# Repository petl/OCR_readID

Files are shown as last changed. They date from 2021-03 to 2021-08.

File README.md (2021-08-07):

<p><h2> Motivation </h2> </p>
<p>How do you track people coming and going into rooms during Covid19? Right, you save the RFID tag off their ID card! Thing is, not all IDs have RFID and more so, not all of the tag IDs are easily matched to user IDs.. To get around this we can just take a photo and read off any number we want. That's easy and quickly modifiable for different ID cards.  </p><br>
<p>Long story short: The project uses <a href='https://github.com/tesseract-ocr/tesseract'>tesseract</a> to do optical character recognition (OCR) on a photo taken from the ID card. This is then fed into a server which saves the original picture with the read number.</p><br>

<p>If you're interested in this project, take a look at the <a href='https://quiescentcurrent.com/blog/post.php?p_id=66'>blog post</a> or just write a message or leave a comment. </p><br><br>

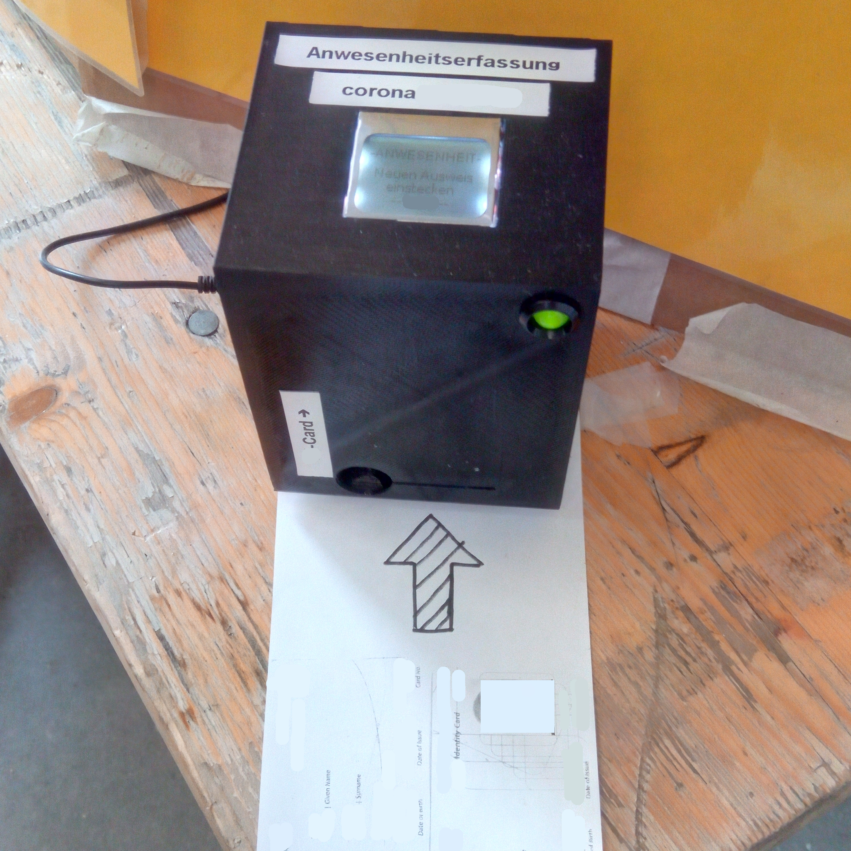
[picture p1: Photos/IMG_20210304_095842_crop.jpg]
<p align="right"><br>Photo of the reader in action.</p>  <br />

<p><h2> Hardware </h2> </p>

<p>The stuff you have to buy is quite straight forward:  <br>
 <ul>
  <li>Raspberry Pi zero with SD card</li>
  <li>Raspberry Pi cam </li>
  <li>Display Nokia 5110 / PCD8544 </li>
  <li>2x LED white</li>
  <li>1x LED greed/red</li>
  <li>3x 220 Ohm resistors </li>
  <li>2.5mm DC barrel connector </li>
  <li>Some wires and heatshrink tube</li>
  <li>4x M3x12 screws</li>
</ul> <br>
I'm not including part numbers as most of the stuff was bought from ebay and can be found by posting the description in the searchbar will find the cheapest option. <br>
</p>

<p><h2> 3D printed hardware </h2> </p>

<p>
The case is made out of two 3D printed parts. They are optimized to use as little filament as possible and don't need any support while printing. <br><br>
If you take a look at the rendering, you can see that the case is mostly empty. The inner chamber is on the top equipped with the camera and one or two LEDs and on the bottom the ID card can slide in from the front. This ensures that the camera always has the same perspective and reading stuff off the picture is straight forward. Around the inner chamber I've left enough space to fit in all the electronics and wires. The final design has two sand filled bags on each side to weigh everything down. Otherwise the box gets shifted around while inserting the ID and feels quite flimsy. 

</p>
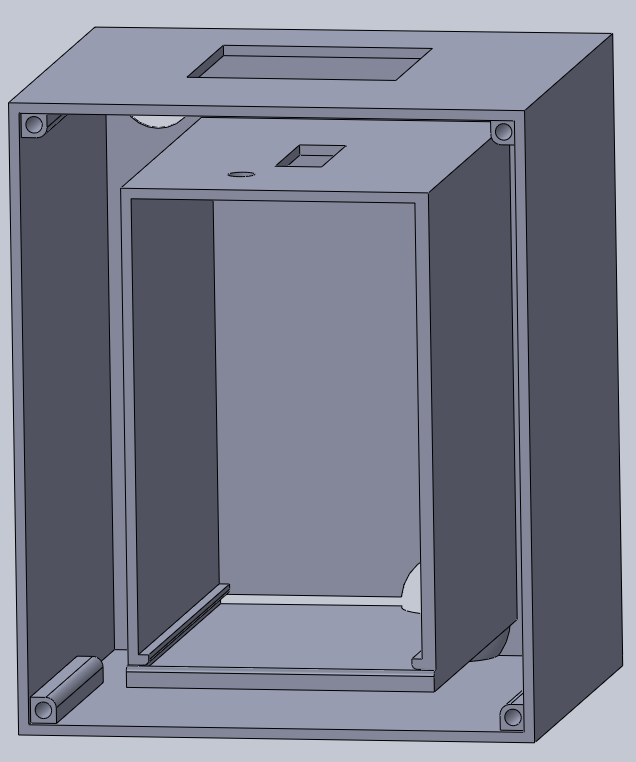
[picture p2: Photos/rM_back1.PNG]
<p align="right"><br>Rendering of the main 3D printed part. </p>  <br />

<p><h2> Electronics </h2> </p>

<p>
The reader was designed to use as little electronics as possible. This reflects in not using an eject mechanism or endswitch for card detection. It has an old Nokia 5110 Display which is super cheap on ebay and a two colour LED for user feedback. There are no buttons or any option for the user to interact with the unit, besides pushing in an ID. The schematics are below, note that the two white LEDs are just for illumination purposes.
</p>
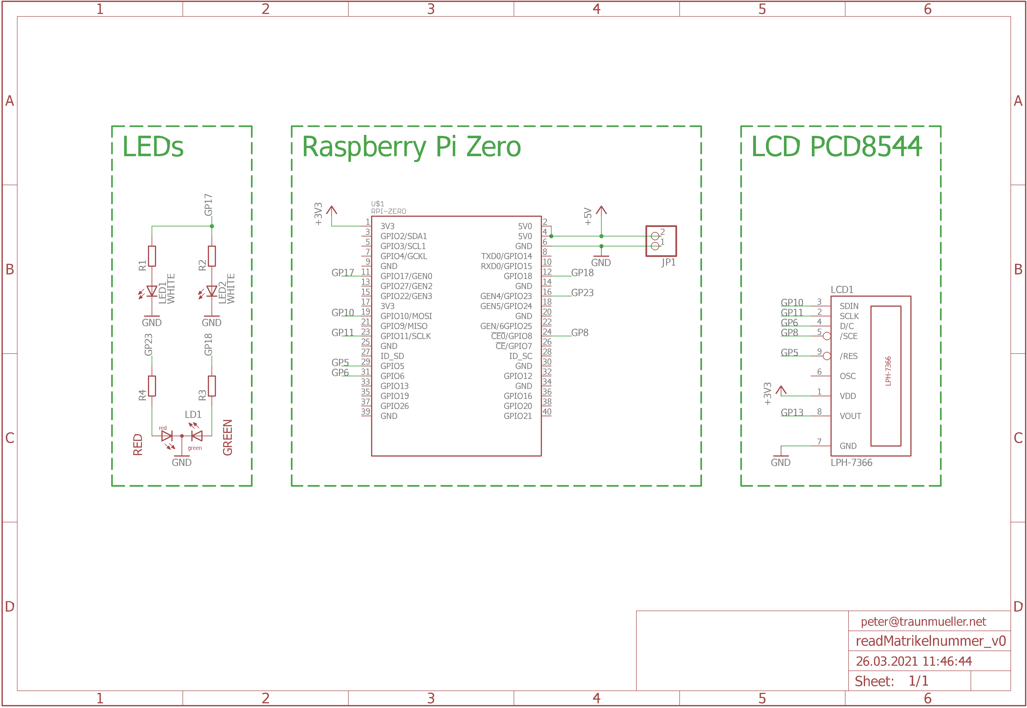
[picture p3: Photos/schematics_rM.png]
<p align="right"><br>Schematics. </p>  <br />

<p><h2> Software </h2> </p>

<p>
Obviously all the code is written in python. Actually it's not that obvious, but there is a nice library doing most of the tesseract interaction for me, so that's that. Please note that the guide includes training data. I've trained the tesseract according to some tutorial and would not recommend you doing so unless you have a good set to start with. I've done training with a limited set of a few cards and it actually made the OCR worse. To get everything running, you can work your way down this list: <br>
 <ul>
  <li><a href='https://projects.raspberrypi.org/en/projects/raspberry-pi-setting-up'>set up the RPi</a>  </li>
  <li>> sudo apt get update && upgrade </li>
  <li>> sudo apt-get install tesseract-ocr </li>
  <li>> sudo apt-get install python3-pip </li>
  <li>> sudo pip3 install pytesseract </li>
  <li>> sudo pip3 install picamera </li>
  <li>> sudo pip3 install adafruit-circuitpython-pcd8544 </li>
  <li>> sudo apt-get install ttf-dejavu </li>
  <li>> sudo apt-get install python3-pil </li>
  <li>optionally, if you have training data: > sudo cp /home/pi/tesseract_training/tesstrain/data/USERcard.traineddata  /usr/share/tesseract-ocr/4.00/tessdata/ </li>
</ul> <br>
</p>

<p>To run the code, start it with start_readMatrikelnummer.sh from the <a href='https://github.com/petl/OCR_readID/tree/main/RPi'>githubi</a>.<br>
It continuously takes photos of the chamber and compared the right most edge brightness to a set value. If this gets bright enough, it takes a photo. This is shown by blinking the red/green LEDs and the photo is saved. After the Photo is taken, the display tells you to take out the card and stops the blinking. Parallel to that it cuts out the part of the image where the interesting number could be and does an OCR on that. If it doesn't detect a plausible number, it takes a second part of the image and does the OCR there. This routine can be expanded infinitely for different cards with different positions for the numbers. If it at some point detects a valid number it opens a URL to upload the number and corresponding image to a server via PHP. </p><br>

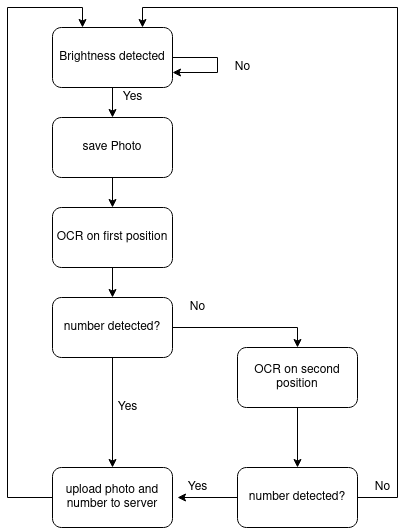
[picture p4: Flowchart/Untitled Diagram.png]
<p align="right"><br>Flowchart for the code. </p>  <br />

<p><h2> Server  </h2> </p>

<p>
If a plausible input is detected, the image and number get uploaded to a server via PHP. The server side is really low level and doesn't need a database or any other thing besides PHP. It checks all the uploaded items for their creation date everythime someone opens the page and deletes everything that is older than 14days.
</p>
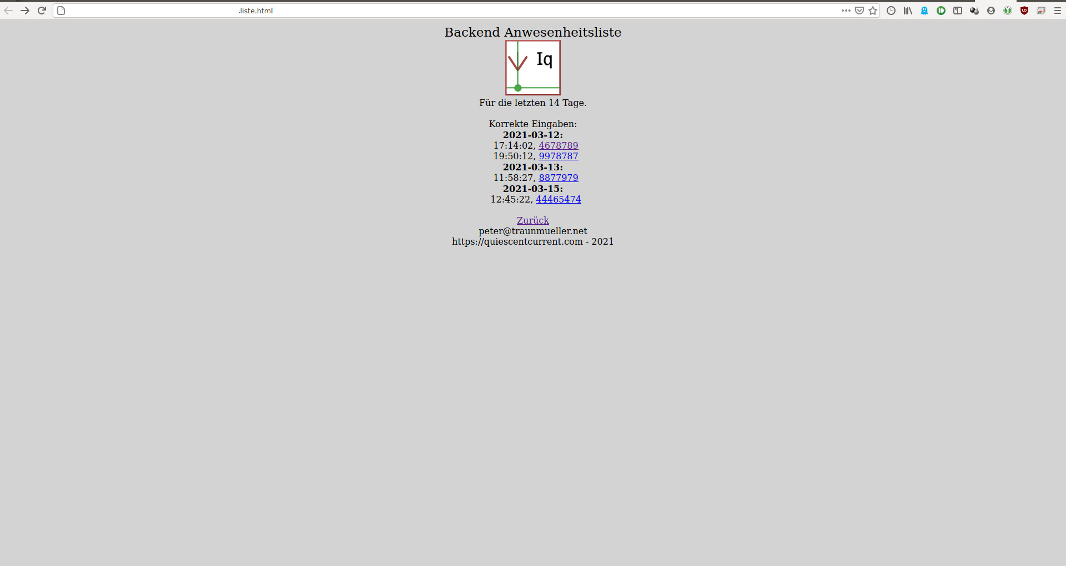
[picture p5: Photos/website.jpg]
<p align="right"><br>Backend on the server. </p>  <br />

<p><h2> Assembly </h2> </p>

<p>
Bringing everything together is not difficult and only requires some hot glue. Due to the spacious inner part of the box, all the cables and the pi perfectly fit with still some space left. 
</p>
<p align="right"><br>Half assembled unit. </p>  <br />
The additional space is then filled with two sand filled bags to make the unit heavier and give it a more robust feeling. <br>
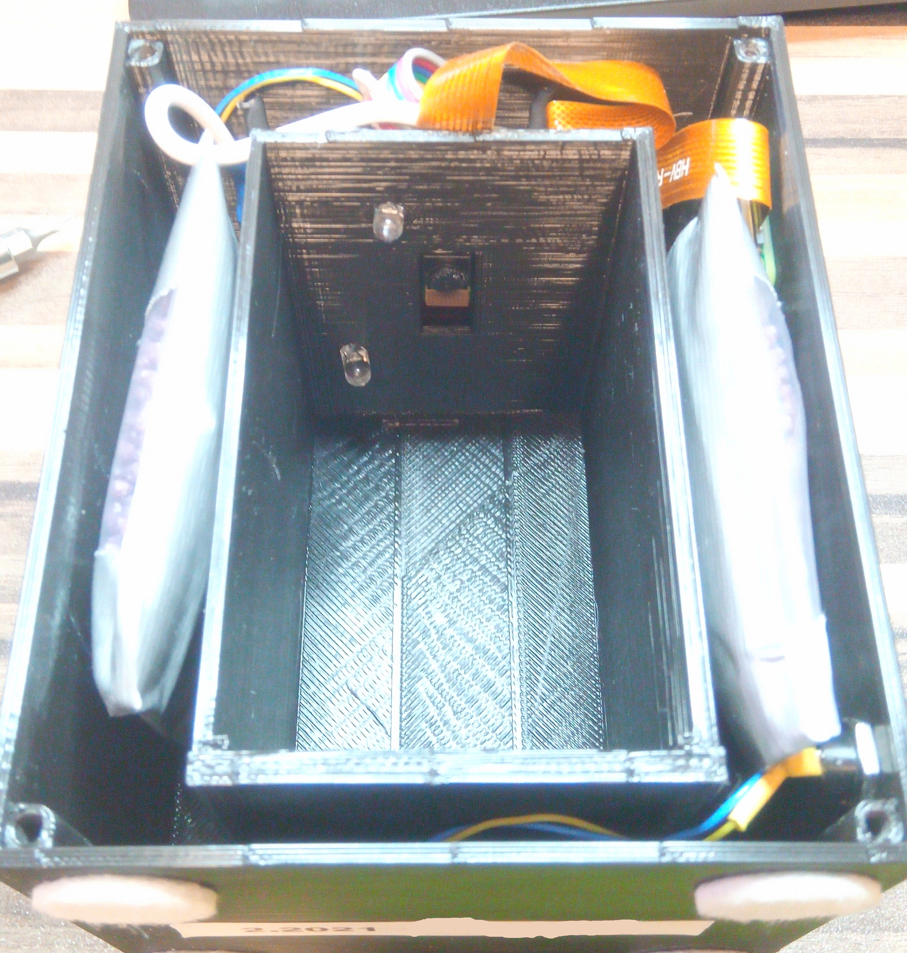
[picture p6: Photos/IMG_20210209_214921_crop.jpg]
<p align="right"><br>Unit with sand bags in place. </p>  <br />

<p><h2> Conclusion </h2> </p>

So that's that, I hope this guide didn't get too long. All the files are on <a href='https://quiescentcurrent.com/blog/post.php?p_id=66'>blog</a> so you can download them and browse through. If you have any questions or feedback just write a message or leave a comment <3

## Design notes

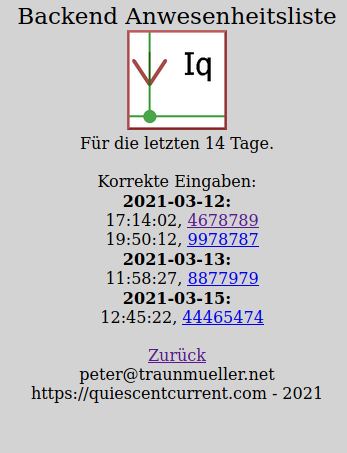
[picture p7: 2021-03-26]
Photos/Screenshot from 2021-03-26 15-51-58.png

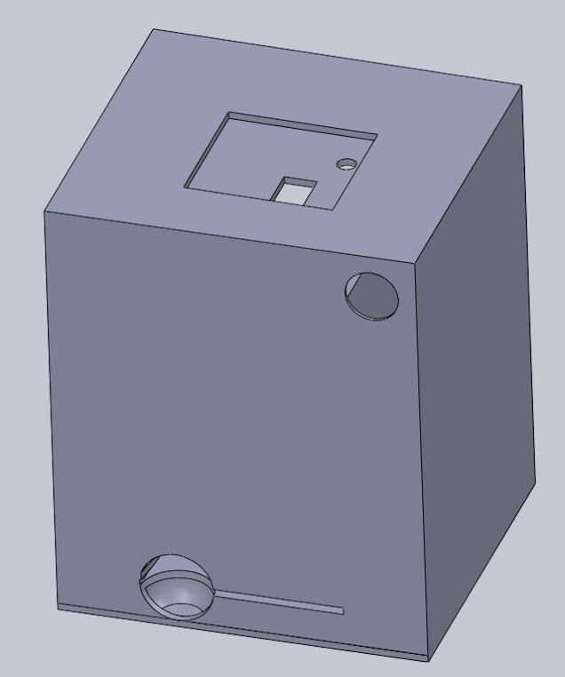
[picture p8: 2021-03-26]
Photos/rM_front1.PNG

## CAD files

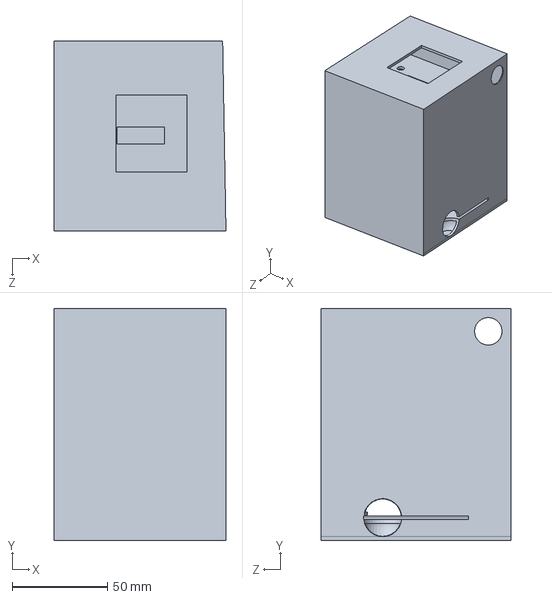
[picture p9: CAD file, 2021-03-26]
Mechanics/solidworks/base_3d_friendly.sdl.SLDPRT
90.4 x 122.0 x 100.0 mm

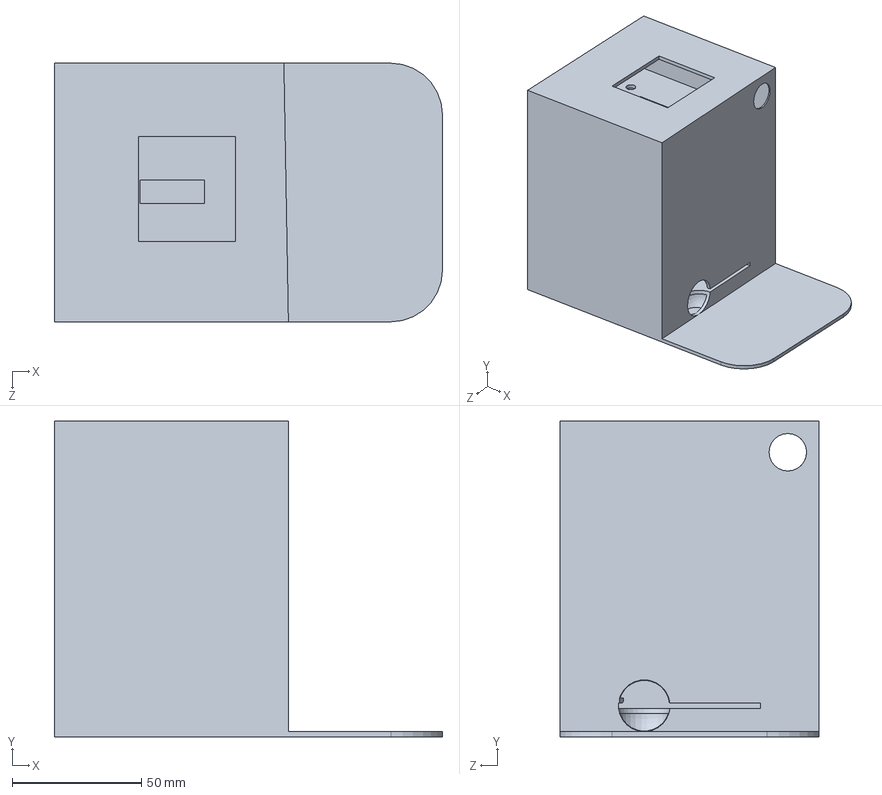
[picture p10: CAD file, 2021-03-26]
Mechanics/solidworks/base.SLDPRT
150.0 x 122.0 x 100.0 mm

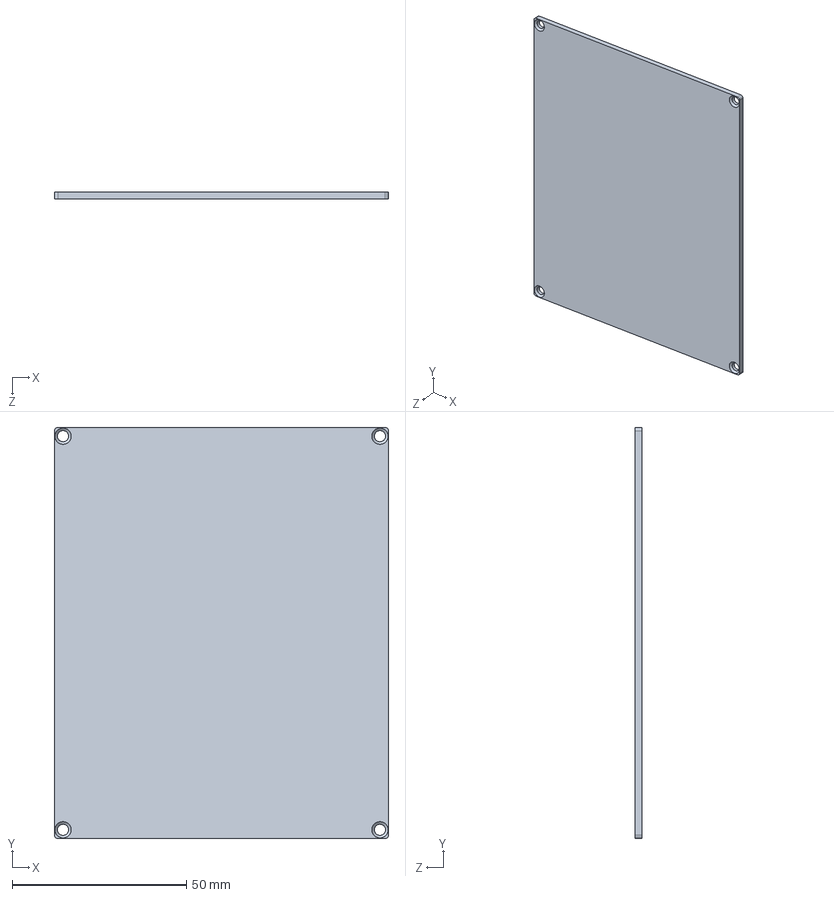
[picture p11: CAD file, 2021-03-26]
Mechanics/solidworks/back_lid.SLDPRT
96.0 x 118.0 x 2.00 mm

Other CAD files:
Mechanics/stl/back_lid.STL
Mechanics/stl/base.STL
Mechanics/stl/base_3d_friendly.sdl.STL

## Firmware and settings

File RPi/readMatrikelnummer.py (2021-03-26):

##Script to read a photo from the raspberry camera and try to extract a Matrikelnummer
#9.2020 peter@traunmueller.net


from PIL import Image, ImageDraw, ImageFont, ImageStat, ImageEnhance, ImageFilter
import pytesseract
from picamera import PiCamera
import time
from io import StringIO
import subprocess
import os
from datetime import datetime
import board
import busio
import digitalio
import adafruit_pcd8544
import threading
import requests
import re

# Motion detection settings
#how white an imgae has to be to be recognised as a TUcard
sensitivity = 100

# File settings
saveWidth = 360
saveHeight = 240
diskSpaceToReserve = 40 * 1024 * 1024 # Keep 40 mb free on disk

#LEDs
LED_white = digitalio.DigitalInOut(board.D17)
LED_white.switch_to_output()
LED_white.value = True
LED_green = digitalio.DigitalInOut(board.D18)
LED_green.switch_to_output()
LED_green.value = False
LED_red = digitalio.DigitalInOut(board.D23)
LED_red.switch_to_output()
LED_red.value = False

#LCD
BORDER = 5
FONTSIZE = 10
spi = busio.SPI(board.SCK, MOSI=board.MOSI)
dc = digitalio.DigitalInOut(board.D6)  # data/command
cs = digitalio.DigitalInOut(board.CE0)  # Chip select
reset = digitalio.DigitalInOut(board.D5)  # reset
display = adafruit_pcd8544.PCD8544(spi, dc, cs, reset)
display.bias = 4
display.contrast = 60
backlight = digitalio.DigitalInOut(board.D13)  # backlight
backlight.switch_to_output()
backlight.value = False #false is ON
display.fill(0)
display.show()
image = Image.new("1", (display.width, display.height))
draw = ImageDraw.Draw(image)
font = ImageFont.truetype("/usr/share/fonts/truetype/dejavu/DejaVuSans.ttf", FONTSIZE)

starttime = int(round(time.time() * 1000))

#the image taker and number reader
def readMatrikelnummer(filename):
    #camera.capture('1.jpg')
    #filename = "./photos/20210208-003515.jpg"
    print(filename)
    nowtime= int(round(time.time() * 1000))
    print("Ausweis gelesen. " )#+ str(nowtime-starttime))
    draw.text(
        (0, 10),
        "Ausweis gelesen.",
        font=font,
        fill=255,
    )
    draw.text(
        (0, 20),
        "Bitte rausziehen.",
        font=font,
        fill=255,
    )
    draw.text(
        (0, 30),
        "Bildanalyse",
        font=font,
        fill=255,
    )
    display.image(image)
    display.show()

    global blinkLEDsON #otherwise it would be a local variable with the same name
    blinkLEDsON = 1

    #is it a new TUCard ?
    im = Image.open(filename)
    print("Neuer Ausweis?")
    im1 = im.crop((40, 290, 260, 335)) #left, top, right, bottom    im1.save("1_nr.jpg")
    #blur filter
    #im1 = im1.filter(ImageFilter.BLUR)
    #im1 = im1.filter(ImageFilter.EDGE_ENHANCE)
    im1 = im1.filter(ImageFilter.MinFilter(3))
    #enhancer
    #enhancer = ImageEnhance.Contrast(im1)
    #factor = 3
    #im1 = enhancer.enhance(factor)
    im1.save("1_nr_neuerAusweis.jpg")
    #custom_config = r'-l TUcard --psm 7 --oem 1 outputbase digits'
    custom_config = r' --psm 7 --oem 1 outputbase digits'
    text = pytesseract.image_to_string(im1, config=custom_config)
    print(text)
    matrnr = re.match(r"([0-9]+)", text, re.I)
    if matrnr:
        matrnr = matrnr.groups()[0]
    else:
        matrnr = "0"
    if len(matrnr) < 7 or len(matrnr) > 8: #matrnr are between 7 and 8 digits
        matrnr = "0"
    print(matrnr)

    draw.text(
        (0, 30),
        "Bildanalyse...alt?",
        font=font,
        fill=255,
    )
    display.image(image)
    display.show()

    #is it an old TUCard ?
    if(matrnr == "0"):
        print("Alter Ausweis?")
        im1 = im.crop((400, 355, 620, 395)) #left, top, right, bottom
        #blur filter
        #im1 = im1.filter(ImageFilter.BLUR)
        #im1 = im1.filter(ImageFilter.EDGE_ENHANCE)
        im1 = im1.filter(ImageFilter.MinFilter(3))
        #enhancer
        #enhancer = ImageEnhance.Contrast(im1)
        #factor = 3
        #im1 = enhancer.enhance(factor)
        im1.save("1_nr_alterAusweis.jpg")

        text = pytesseract.image_to_string(im1, config=custom_config)
        print(text)

        matrnr = re.match(r"([0-9]+)", text, re.I)
        if matrnr:
            matrnr = matrnr.groups()[0]
        else:
            matrnr = "0"
        if len(matrnr) < 7 or len(matrnr) > 8: #matrnr are between 7 and 8 digits
            matrnr = "0"
        print(matrnr)

    #the numbers never start with a "4", but often "1" gets recognized as "4"
    if str(matrnr)[0] == "4":
        print("corrected a leading '4' to a '1'")
        matrnr = str(matrnr)
        matrnr = "1" + matrnr[1:]
    #print(matrnr)

    ##boxes = pytesseract.image_to_boxes('1.jpg', config=custom_config)
    #print(boxes)

    nowtime= int(round(time.time() * 1000))
    print("Hallo " + str(matrnr) + "!")# + str(nowtime-starttime))

    draw.rectangle((0,0,display.width,display.height), outline=0, fill=0) # clear image
    draw.text( (20, 10),"Hallo!",font=font,fill=255)
    draw.text( (20, 20),str(matrnr),font=font,fill=255)
    draw.text( (20, 30),"eingetragen",font=font, fill=255)
    display.image(image)
    display.show()
    blinkLEDsON = 0
    time.sleep(2)


    print("Formated MatrNr:"+str(matrnr))
    #return what we've done
    if len(matrnr) < 7 or len(matrnr) > 8: #matrnr are between 7 and 8 digits
        return 0
    else:
        return matrnr

def uploadData(filename, matrnr):
    print("Upload to server")
    url = 'https://quiescentcurrent.com/da/readerUpload/uploadFromPi.php'
    post_files = {'fileToUpload': open(filename, 'rb')}
    post_data = { 'MatrNr' :  matrnr}
    r = requests.post(url, data = post_data,  files=post_files)
    #print(r.text)

def blinkLEDs():
    while True:
        if blinkLEDsON == 1:
            LED_red.value = False
            LED_green.value = True
            time.sleep(0.2)
            LED_red.value = True
            LED_green.value = False
            time.sleep(0.2)


# Capture a small test image (for motion detection)
def captureTestImage():
    #command = "raspistill -w %s -h %s -t 0 -e bmp -o -" % (100, 75)
    #imageData = StringIO()
    #imageData.write(subprocess.check_output(command, shell=True))
    #imageData.seek(0)
    camera.capture('reference_Image.jpg')
    im = Image.open('reference_Image.jpg')
    im_compare = im.crop((560, 300, 600, 350)) #left, top, right, bottom
    im_compare.save("im_compare.jpg")
    buffer = im_compare.load()
    return im_compare, buffer

# Save a full size image to disk
def saveImage(width, height, diskSpaceToReserve):
    time = datetime.now()
    filename = "./photos/%04d%02d%02d-%02d%02d%02d.jpg" % (time.year, time.month, time.day, time.hour, time.minute, time.second)
    camera.capture(filename)
    return filename
    #print("Captured %s" % filename)
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

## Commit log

2021-03-26 added mechanical files
    [back_lid.SLDPRT, back_lid.STL, base.SLDPRT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]
2021-03-26 added schematics
2021-03-26 added flowchart
2021-03-26 photo of schematics
